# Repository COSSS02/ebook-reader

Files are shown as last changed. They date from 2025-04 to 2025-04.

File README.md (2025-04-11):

# E-book Reader

This is my implementation of an E-book Reader, made entirely in Autodesk Fusion.

## Device
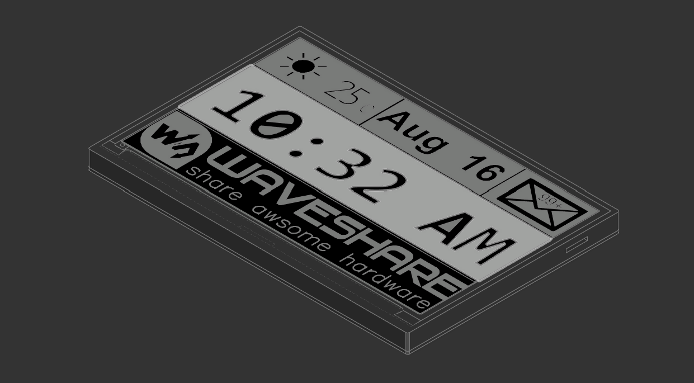
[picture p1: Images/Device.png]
Device


## Exploded View
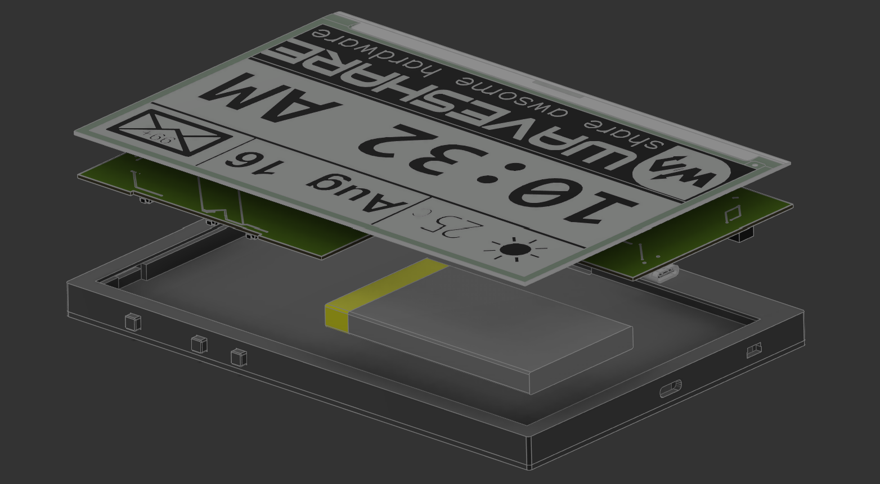
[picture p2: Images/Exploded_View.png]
Exploded


## PCB
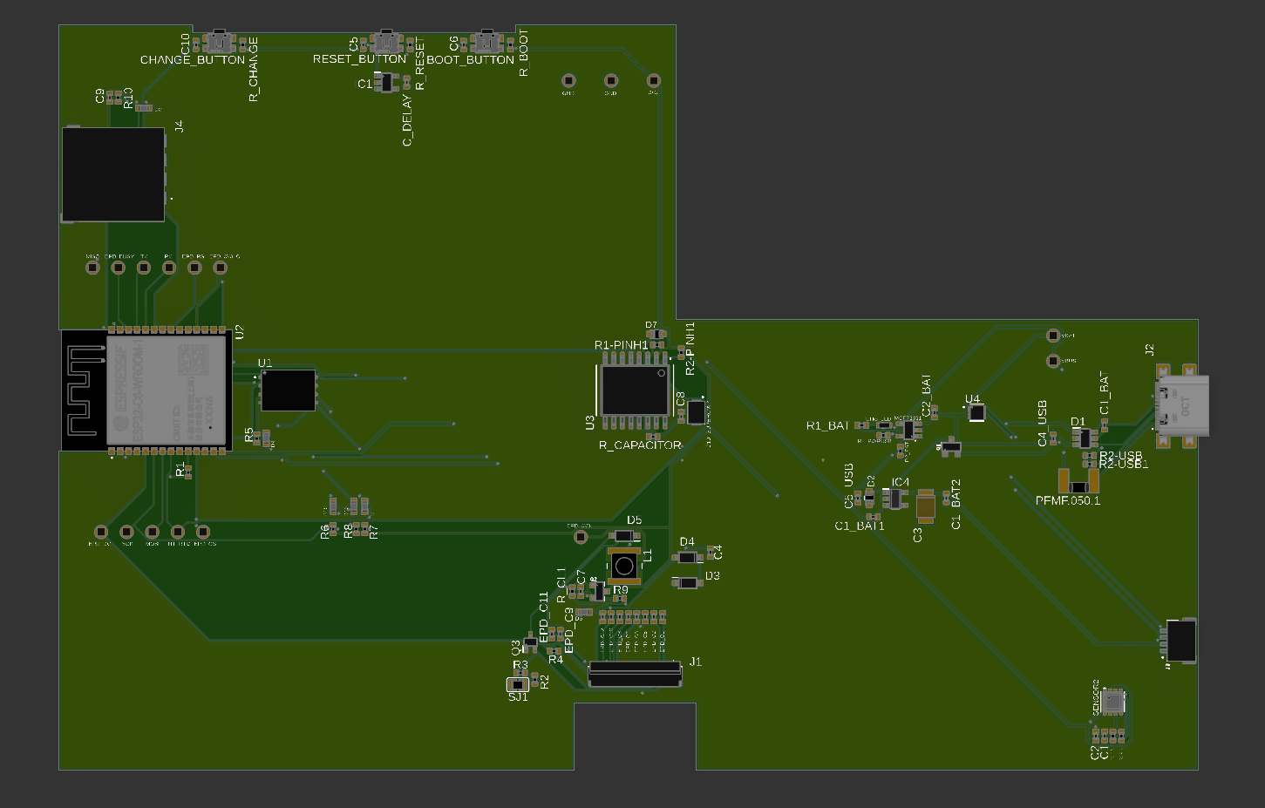
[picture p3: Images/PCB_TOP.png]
PCB


## Block Diagram
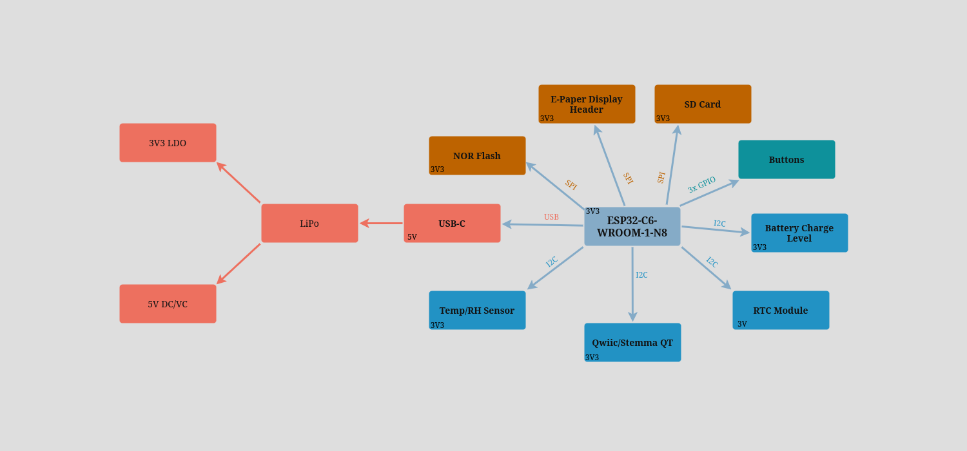
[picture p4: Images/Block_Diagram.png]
Diagram


## ESP32-C6 Pin Connections

### E-Paper Display
- MOSI --> GPIO4
- SCK --> GPIO5
- RESET --> GPIO15
- BUSY --> GPIO16
- CS --> GPIO17
- DC --> GPIO18

### SD Card
- CLK --> GPIO6
- CMD --> GPIO7
- DATA0 --> GPIO8
- DATA1 --> GPIO9
- DATA2 --> GPIO10
- DATA3 --> GPIO11

### NOR Flash Memory
- MOSI --> GPIO4
- MISO --> GPIO3
- CLK --> GPIO5
- CS --> GPIO2

### Temp/RH Sensor
- SDA --> GPIO19
- SCL --> GPIO20

### RTC Module
- SDA --> GPIO19
- SCL --> GPIO20

### Qwiic / Stemma QT
- SDA --> GPIO19
- SCL --> GPIO20

### Battery Charge Level
- SDA --> GPIO19
- SCL --> GPIO20

### Buttons
- Reset --> GPIO0
- Boot --> GPIO1

## Bill of Materials

| Component | Datasheet |
|---|---|
| ESP32-C6-WROOM-1-N8 | [Mouser](https://mou.sr/42swLfH) |
| FH34SRJ-24S-0.5SH | [Mouser](https://mou.sr/43Cr53R) |
| XC6220A331MR-G | [Mouser](https://mou.sr/4ieKgVa) |
| MAX17048G+T10 | [Mouser](https://mou.sr/3FWR5wY) |
| W25Q512JVEIQ | [Mouser](https://mou.sr/42vsB6J) |
| USB4110-GF-A | [Mouser](https://mou.sr/4iUMo5l) |
| USBLC6-2SC6Y | [Mouser](https://mou.sr/42lyiTK) |
| DS3231SN# | [Mouser](https://mou.sr/42jhNr4) |
| BME680 | [Mouser](https://mou.sr/42kgEzJ) |
| PFMF.050.2 | [Mouser](https://mou.sr/4cjORnD) |
| BD5229G-TR | [Mouser](https://mou.sr/3EckiDF) |
| MBR0530-TP | [Mouser](https://mou.sr/4i9Ddgn) |
| DMG2305UX-7 | [Mouser](https://mou.sr/4ci24gy) |
| PGB1010603MR | [Mouser](https://mou.sr/3Yg9sDe) |
| Adafruit 4208 | [Mouser](https://mou.sr/4lcY19f) |
| SD0805S020S1R0 | [Mouser](https://mou.sr/4cljSYj) |
| SI1308EDL-T1-GE3 | [Mouser](https://mou.sr/4lj7JXH) |
| MCP73831-2ACI/MC | [Mouser](https://mou.sr/3XJhnsM) |

## Hardware Description

### Main Controller

    ESP32-C6-WROOM-1-N8: RISC-V based microcontroller with WiFi 6 and Bluetooth 5.0 LE

    Operating Voltage: 3.3V

    Clock Speed: 160MHz

### Memory Configuration

    External NOR Flash: W25Q512JVEIQ (64MB capacity)

    Interface: SPI (Serial Peripheral Interface)

### Power Management System

    Primary Regulator: XC6220A331MR-G (3.3V LDO)

    Battery Charger: MCP73831 (Li-Po charging controller)

    Fuel Gauge: MAX17048G+T10 (Battery monitoring IC)

    Power Path Protection:

        MBR0530 Schottky diodes (x3)

        SI1308EDL-T1-GE3 MOSFET

### Display System

    E-Paper Display Interface: Dedicated header with ESD protection

    Display Driver Circuit: Custom EPD power management

    Control Signals:

        EPD_RST (Reset)

        EPD_BUSY (Status)

        EPD_DC (Data/Command)

        EPD_CS (Chip Select)

### Environmental Sensing

    BME688: Integrated environmental sensor with:

        Temperature

        Humidity

        Barometric pressure

        Air quality (VOC detection)

    Interface: I2C (Qwiic/Stemma QT compatible)

### Real-Time Clock

    DS3231SN: High-precision RTC with:

        ±2ppm accuracy

        Integrated temperature compensation

        Battery backup support

        Square wave/interrupt output

### Connectivity Interfaces USB

    Type-C Connector: USB 2.0 compliant

    ESD Protection: USBLC6-2SC6Y

    Data Lines:

        USB_D+

        USB_D-

### Expansion Ports

    Qwiic/Stemma QT: 4-pin I2C connector

    SD Card Slot: Supports standard SD cards

        Interface: SPI mode

        Detection switch included

### Debugging Interfaces

    Test Points: 17 accessible test points

### Power Specifications

    Input Voltage: 5V via USB-C

    Battery Voltage: 3.7V Li-Po

    Power Tree:

        Primary 3.3V rail for digital components

        Dedicated 3.3V rail for display

        RTC backup power circuit

### Mechanical Interfaces

    24-pin FH34SRJ Connector: Display interface

    Tactile Buttons:

        Reset button

        Boot/IO button

        Custom function buttons

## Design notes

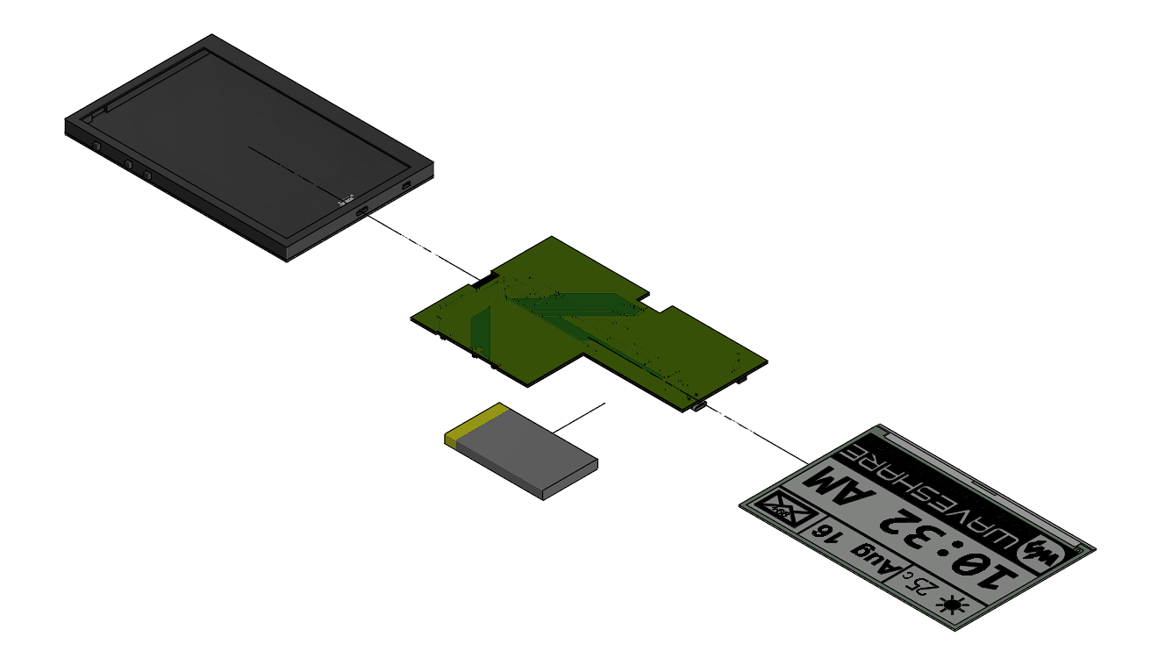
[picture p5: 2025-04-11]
Images/Exploded_View_Drawing.png

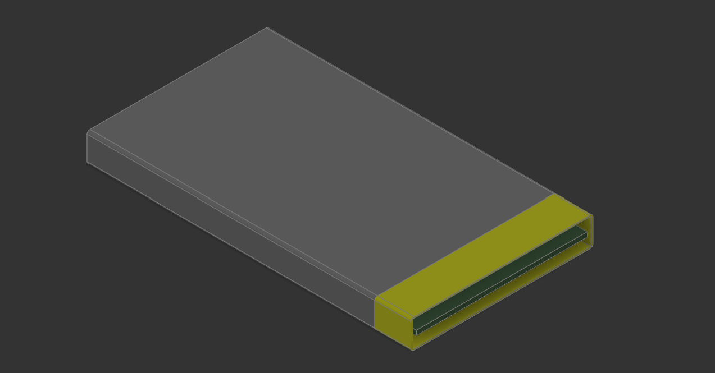
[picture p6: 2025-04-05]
Images/Battery.png

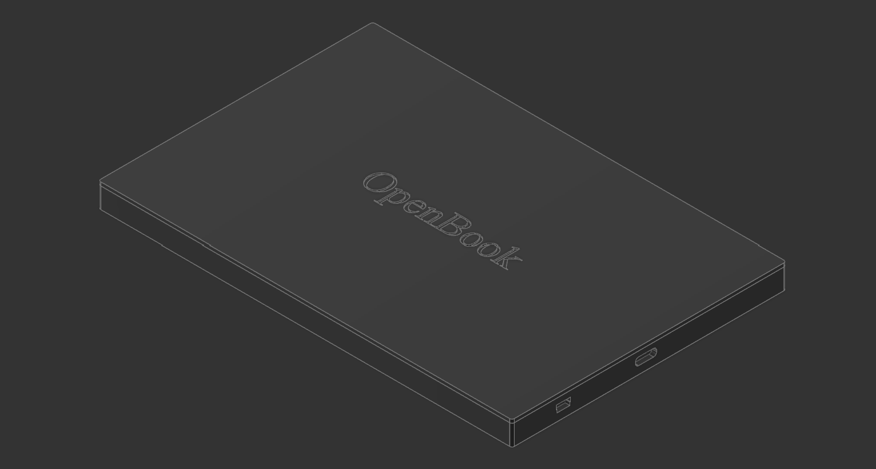
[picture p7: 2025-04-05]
Images/Enclosure.png

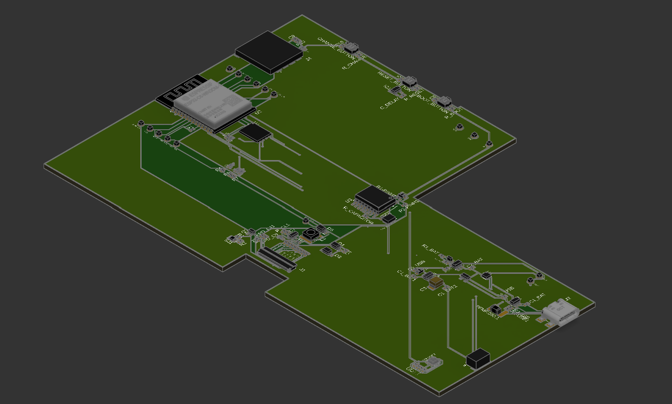
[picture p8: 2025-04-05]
Images/PCB.png

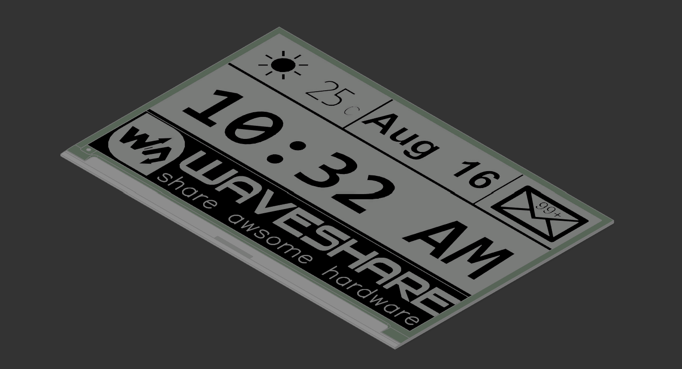
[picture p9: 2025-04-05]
Images/Display.png

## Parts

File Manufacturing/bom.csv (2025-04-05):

Qty | Value | Device | Package | Parts | Description | ARROW_PART_NUMBER | ARROW_PRICE-STOCK | AVAILABILITY | CHECK_PRICES | COPYRIGHT | DESCRIPTION | FOOPRINT | FOOTPRINT | HEIGHT | MANUFACTURER_NAME | MANUFACTURER_PART_NUMBER | MF | MFR_NAME | MOUSER_PART_NUMBER | MOUSER_PRICE-STOCK | MOUSER_TESTING_PART_NUMBER | MOUSER_TESTING_PRICE-STOCK | MP | PACKAGE | POPULARITY | PRICE | PROD_ID | PURCHASE-URL | SNAPEDA_LINK | SPICEPREFIX | VAL | VALUE
1 |  | ADAFRUIT_LEDCHIP-LED0603 | ADAFRUIT_CHIP-LED0603 | CHG_LED | LED
1 |  | SJ | SJ | SJ1 | SMD solder JUMPER |  |  |  |  |  |  |  |  |  |  |  |  |  |  |  |  |  |  |  | 3
1 | 0.1uF/50V | ESP32_WROVER_EAGLE-LTSPICE_C | EAGLE-LTSPICE_C0402 | EPD_C5 | CAPACITOR, European symbol
1 | 0.47 | ESP32_WROVER_EAGLE-LTSPICE_R | ESP32_WROVER_EAGLE-LTSPICE_R0402 | R3 | RESISTOR, European symbol
1 | 100K | ESP32_WROVER_EAGLE-LTSPICE_R | ESP32_WROVER_EAGLE-LTSPICE_R0402 | R1_PWRUSB | RESISTOR, European symbol
8 | 100nF | ESP32_WROVER_EAGLE-LTSPICE_C | EAGLE-LTSPICE_C0402 | C1, C2, C4_USB, C6, C8, C9, C10, C_DELAY | CAPACITOR, European symbol
1 | 100uF TANT | RCL_CPOL-EUCT3528 | RCL_CT3528 | C3 | POLARIZED CAPACITOR, European symbol |  |  |  |  |  |  |  |  |  |  |  |  |  |  |  |  |  |  |  | 0 |  |  |  |  | C
2 | 10K | ESP32_WROVER_EAGLE-LTSPICE_R | ESP32_WROVER_EAGLE-LTSPICE_R0402 | R1, R4 | RESISTOR, European symbol
14 | 10k | ESP32_WROVER_EAGLE-LTSPICE_R | ESP32_WROVER_EAGLE-LTSPICE_R0402 | R1-PINH, R1-PINH1, R2-PINH, R2-PINH1, R5, R6, R7, R8, R9, R10, R_BOOT, R_CHANGE, R_CL1, R_RESET | RESISTOR, European symbol
1 | 10uF | ESP32_WROVER_EAGLE-LTSPICE_C | EAGLE-LTSPICE_C0402 | C7 | CAPACITOR, European symbol
1 | 112A-TAAR-R03_ATTEND | 112A-TAAR-R03_ATTEND | 112ATAARR03ATTEND | J4 | Micro SD Card Socket, Push-Push Type, Top Mount, SMT, H=1.83mm, 10u |  |  |  |  |  | Micro SD Card Socket | Push-Push Type | Top Mount | SMT | H=1.83mm | 10u |  |  | 1.9mm | ATTEND | 112A-TAAR-R03 ATTEND
1 | 15 | ESP32_WROVER_EAGLE-LTSPICE_R | ESP32_WROVER_EAGLE-LTSPICE_R0402 | R_CAPACITOR | RESISTOR, European symbol
1 | 1uF | ESP32_WROVER_EAGLE-LTSPICE_C | EAGLE-LTSPICE_C0402 | C5 | CAPACITOR, European symbol
9 | 1uF/50V | ESP32_WROVER_EAGLE-LTSPICE_C | EAGLE-LTSPICE_C0402 | EPD_C1, EPD_C2, EPD_C6, EPD_C7, EPD_C8, EPD_C9, EPD_C10, EPD_C11, EPD_C12 | CAPACITOR, European symbol
1 | 2.2 | ESP32_WROVER_EAGLE-LTSPICE_R | ESP32_WROVER_EAGLE-LTSPICE_R0402 | R2 | RESISTOR, European symbol
1 | 200 | ESP32_WROVER_EAGLE-LTSPICE_R | ESP32_WROVER_EAGLE-LTSPICE_R0402 | R1_BAT | RESISTOR, European symbol
2 | 20V/4.2A/52mO/1.4W | ESP32_WROVER_SPARKFUN-DISCRETESEMI_MOSFET_PCH | ESP32_WROVER_SPARKFUN-DISCRETESEMI_SOT23-3 | Q1, Q2 | P-channel MOSFETs |  |  |  |  |  |  |  | DMG2305UX-7
1 | 2K | ESP32_WROVER_EAGLE-LTSPICE_R | ESP32_WROVER_EAGLE-LTSPICE_R0402 | R2_BAT | RESISTOR, European symbol
5 | 4.7uF | ESP32_WROVER_EAGLE-LTSPICE_C | EAGLE-LTSPICE_C0402 | C1_BAT, C1_BAT1, C1_BAT2, C2_BAT, C5_USB | CAPACITOR, European symbol
1 | 4.7uF/25V | ESP32_WROVER_EAGLE-LTSPICE_C | EAGLE-LTSPICE_C0402 | C4 | CAPACITOR, European symbol
2 | 5k1 | ESP32_WROVER_EAGLE-LTSPICE_R | ESP32_WROVER_EAGLE-LTSPICE_R0402 | R2-USB, R2-USB1 | RESISTOR, European symbol
1 | 744043680IND_4828-WE-TPC_WRE | 744043680IND_4828-WE-TPC_WRE | IND_4828-WE-TPC_WRE | L1 |  |  |  |  |  | Copyright (C) 2024 Ultra Librarian. All rights reserved. |  |  |  |  |  | 744043680 |  | Wurth Electronics |  |  |  |  |  |  |  |  |  |  |  |  | 68uH
1 | BD5229G-TR | BD5229G-TR | SOT95P280X125-5N | IC1 | Voltage Detector with Adjustable Delay Time: CMOS processes are utilized to develop high precision, low current consumption CMOS reset ICs that allow arbitrary setting of the delay time. The extensive lineup includes both Nch Open Drain and CMOS output types in a wide range of detection voltages (from 2.3V to 6.0V, in 0.1V steps), enabling selection of the ideal solution based on customer requirements. In addition, the entire series is of course both lead-free and RoHS-compliant. |  |  |  |  |  | Voltage Detector with Adjustable Delay Time: CMOS processes are utilized to develop high precision | low current consumption CMOS reset ICs that allow arbitrary setting of the delay time. The extensive lineup includes both Nch Open Drain and CMOS output types in a wide range of detection voltages (from 2.3V to 6.0V | in 0.1V steps) | enabling selection of the ideal solution based on customer requirements. In addition | the entire series is of course both lead-free and RoHS-compliant. |  |  | 1.25mm | ROHM Semiconductor | BD5229G-TR |  |  | 755-BD5229G-TR | https://www.mouser.co.uk/ProductDetail/ROHM-Semiconductor/BD5229G-TR?qs=4kLU8WoGk0vvnhrrYwdszw%3D%3D
3 | BUTTON_CUSYOMV1FINAL_BUTT | BUTTON_CUSYOMV1FINAL_BUTT | MYBUTTON | BOOT_BUTTON, CHANGE_BUTTON, RESET_BUTTON
1 | CPH3225A | CPH3225A | CAPCP3225X100N | C10_SUPERCAP | Cap 0.011F 3.3V 1210 Flat Check availability |  |  | Not in stock | https://www.snapeda.com/parts/CPH3225A/Seiko+Instruments/view-part/?ref=eda |  | 11 mF (EDLC) Supercapacitor 3.3 V 1210 (3225 Metric) - - |  |  |  |  |  | Seiko Instruments |  |  |  |  |  | CPH3225A | 1210 Seiko |  | None |  | https://www.snapeda.com/api/url_track_click_mouser/?unipart_id=562593&manufacturer=Seiko Instruments&part_name=CPH3225A&search_term=None | https://www.snapeda.com/parts/CPH3225A/Seiko+Instruments/view-part/?ref=snap
1 | DS3231SN# | DS3231SN# | SOIC127P1032X265-16N | U3 | Real Time Clock Serial 16-Pin SOIC W T/R Check availability |  |  | In Stock | https://www.snapeda.com/parts/DS3231SN%23/Analog+Devices/view-part/?ref=eda |  | Extremely Accurate I²C-Integrated RTC/TCXO/Crystal |  |  |  |  |  | Analog Devices |  |  |  |  |  | DS3231SN# | SOIC-16 Maxim |  | None |  | https://www.snapeda.com/api/url_track_click_mouser/?unipart_id=99048&manufacturer=Analog Devices&part_name=DS3231SN#&search_term=None | https://www.snapeda.com/parts/DS3231SN%23/Analog+Devices/view-part/?ref=snap
1 | ESP32-C6-WROOM-1-N8 | ESP32-C6-WROOM-1-N8 | XCVR_ESP32-C6-WROOM-1-N8 | U2 | Check availability |  |  | In Stock | https://www.snapeda.com/parts/ESP32-C6-WROOM-1-N8/Espressif+Systems/view-part/?ref=eda |  | Multiprotocol Modules ESP32-C6 module | Wi-Fi 6 in 2.4 GHz band | Bluetooth 5 | Zigbee 3.0 and Thread. ESP34-WROOM Compatible - ENGINEERING SAMPLE |  |  |  |  |  | Espressif Systems |  |  |  |  |  | ESP32-C6-WROOM-1-N8 | None |  | None |  |  | https://www.snapeda.com/parts/ESP32-C6-WROOM-1-N8/Espressif+Systems/view-part/?ref=snap
1 | ESP32C6_VARISTORCN1812 | ESP32C6_VARISTORCN1812 | ESP32C6_VARISTOR_CT/CN1812 | PFMF.050.1 | VARISTOR |  |  |  |  |  |  |  |  |  |  |  |  |  |  |  |  |  |  |  | 0
2 | ESP32_WROVER_AVX---SD0805S020S1R0_AVX_SD0805S020S1R0_0_0 | ESP32_WROVER_AVX---SD0805S020S1R0_AVX_SD0805S020S1R0_0_0 | ESP32_WROVER_AVX---SD0805S020S1R0_AVX_SD0805S020S1R0_0 | D2, D7 | Schottky Barrier Rectifier Diode |  |  |  |  |  |  | SD0805S020S1R0
1 | ESP32_WROVER_BME680_BME680 | ESP32_WROVER_BME680_BME680 | ESP32_WROVER_BME680_PSON80P300X300X100-8N | SENSOR2 | Integrated Environmental Unit |  |  | Unavailable |  |  | Integrated Environmental Unit |  | BME688 |  |  |  | Bosch Sensortec |  |  |  |  |  | BME680 | LGA-8 Bosch Tools |  | None
1 | ESP32_WROVER_SPARKFUN-IC-POWER_MCP73831 | ESP32_WROVER_SPARKFUN-IC-POWER_MCP73831 | ESP32_WROVER_SPARKFUN-IC-POWER_SOT23-5 | MCP73831 | MCP73831T Li-Ion, Li-Pol Controller |  |  |  |  |  |  |  |  |  |  |  |  |  |  |  |  |  |  |  |  |  | IC-09995
1 | FH34SRJ-24S-0.5SH_99_ | FH34SRJ-24S-0.5SH_99_ | FH34SRJ24S05SH99 | J1 | (0.50mm) Surface Mount, Right Angle |  |  |  |  |  | 24 Position FFC | FPC Connector Contacts | (0.50mm) Surface Mount | Right Angle |  |  | 1.1mm | Hirose | FH34SRJ-24S-0.5SH(99) |  |  | 798-FH34SRJ24S05SH99 | https://www.mouser.co.uk/ProductDetail/Hirose-Connector/FH34SRJ-24S-0.5SH99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
1 | MAX17048G+T10 | MAX17048G+T10 | SON50P200X200X80-9N | U4 | Check availability |  |  | In Stock | https://www.snapeda.com/parts/MAX17048G+T10/Analog+Devices/view-part/?ref=eda |  | 3µA 1-Cell/2-Cell Fuel Gauge with ModelGauge |  |  |  |  |  | Analog Devices |  |  |  |  |  | MAX17048G+T10 | TDFN-8 Maxim |  | None |  | https://www.snapeda.com/api/url_track_click_mouser/?unipart_id=329239&manufacturer=Analog Devices&part_name=MAX17048G+T10&search_term=None | https://www.snapeda.com/parts/MAX17048G+T10/Analog+Devices/view-part/?ref=snap | X
3 | MBR0530MYSOD | MBR0530MYSOD | SOD3716X135N | D3, D4, D5 | ON SEMICONDUCTOR - MBR0530 - DIODE, SCHOTTKY, 0.5A, 30V, SOD-123
6 | PGB1010603MRMYDIOC | PGB1010603MRMYDIOC | DIOC1608X36N | D6, D8, D9, D10, D11, D12 | Check availability
1 | QWIIC_RIGHT_ANGLE | QWIIC_CONNECTORJS-1MM | JST04_1MM_RA | J3 | SparkFun I2C Standard Qwiic Connector |  |  |  |  |  |  |  |  |  |  |  |  |  |  |  |  |  |  |  |  |  | CONN-13694 |  |  |  |  | QWIIC_RIGHT_ANGLE
1 | SAMACSYS_PARTS_USB4110-GF-A | SAMACSYS_PARTS_USB4110-GF-A | SAMACSYS_PARTS_USB4110GFA | J2 | CONN USB 2.0 TYPE-C R/A SMT |  |  |  |  |  | CONN USB 2.0 TYPE-C R/A SMT |  |  | 3.26mm | GCT (GLOBAL CONNECTOR TECHNOLOGY) | USB4110-GF-A |  |  | 640-USB4110-GF-A | https://www.mouser.co.uk/ProductDetail/GCT/USB4110-GF-A?qs=KUoIvG%2F9IlYiZvIXQjyJeA%3D%3D
1 | SI1308EDL-T1-GE3 | SI1308EDL-T1-GE3 | SOT65P210X110-3N | Q3 | MOSFET N-Ch 30V 1.5A TrenchFET SC70 Vishay Si1308EDL-T1-GE3 N-channel MOSFET Transistor, 1.5 A, 30 V, 3-Pin SC-70 |  |  | In Stock | https://www.snapeda.com/parts/SI1308EDL-T1-GE3/Vishay+Siliconix/view-part/?ref=eda |  | Si1308EDL-T1-GE3 N-channel MOSFET Transistor | 1.5 A | 30 V | 3-Pin SC-70 | Siliconix / Vishay SI1308EDL-T1-GE3 |  |  |  |  |  | Vishay Siliconix |  |  |  |  |  | SI1308EDL-T1-GE3 | SOT-323 Vishay Semiconductor |  | None |  | https://www.snapeda.com/api/url_track_click_mouser/?unipart_id=274603&manufacturer=Vishay Siliconix&part_name=SI1308EDL-T1-GE3&search_term=None | https://www.snapeda.com/parts/SI1308EDL-T1-GE3/Vishay+Siliconix/view-part/?ref=snap
17 | TP | TP | TP20R | TP1, TP2, TP3, TP4, TP5, TP6, TP7, TP8, TP9, TP10, TP11, TP12, TP13, TP14, TP15, TP16, TP17 | Test pad
1 | USBLC6-2SC6Y | USBLC6-2SC6Y | SOT95P280X145-6N | D1 | Low Cap. ESD Protection Auto SOT-23-6 STMicroelectronics USBLC6-2SC6Y, Dual Uni-Directional TVS Diode Array, 6-Pin SOT-23 |  |  | In Stock | https://www.snapeda.com/parts/USBLC6-2SC6Y/STMicroelectronics/view-part/?ref=eda |  | 17V Clamp 5A (8/20µs) Ipp Tvs Diode Surface Mount SOT-23-6 |  |  |  |  |  | STMicroelectronics |  |  |  |  |  | USBLC6-2SC6Y | SOT-23-6 STMicroelectronics |  | None |  |  | https://www.snapeda.com/parts/USBLC6-2SC6Y/STMicroelectronics/view-part/?ref=snap
1 | W25Q512JVEIQ | W25Q512JVEIQ | SON127P600X800X80-9N | U1 | Check availability |  |  | In Stock | https://www.snapeda.com/parts/W25Q512JVEIQ/Winbond+Electronics/view-part/?ref=eda |  | FLASH - NOR Memory IC 512Mb (64M x 8) SPI - Quad I/O 133 MHz 8-WSON (8x6) |  |  |  |  |  | Winbond Electronics |  |  |  |  |  | W25Q512JVEIQ | Package |  | None |  |  | https://www.snapeda.com/parts/W25Q512JVEIQ/Winbond+Electronics/view-part/?ref=snap
1 | XC6220A331MR-G | XC6220A331MR-G | SOT95P280X120-5N | IC4 | LDO Voltage Regulators |  |  |  |  |  | LDO Voltage Regulators |  |  | 1.2mm | Torex | XC6220A331MR-G |  |  | 865-XC6220A331MR-G | https://www.mouser.co.uk/ProductDetail/Torex-Semiconductor/XC6220A331MR-G?qs=AsjdqWjXhJ8ZSWznL1J0gg%3D%3D

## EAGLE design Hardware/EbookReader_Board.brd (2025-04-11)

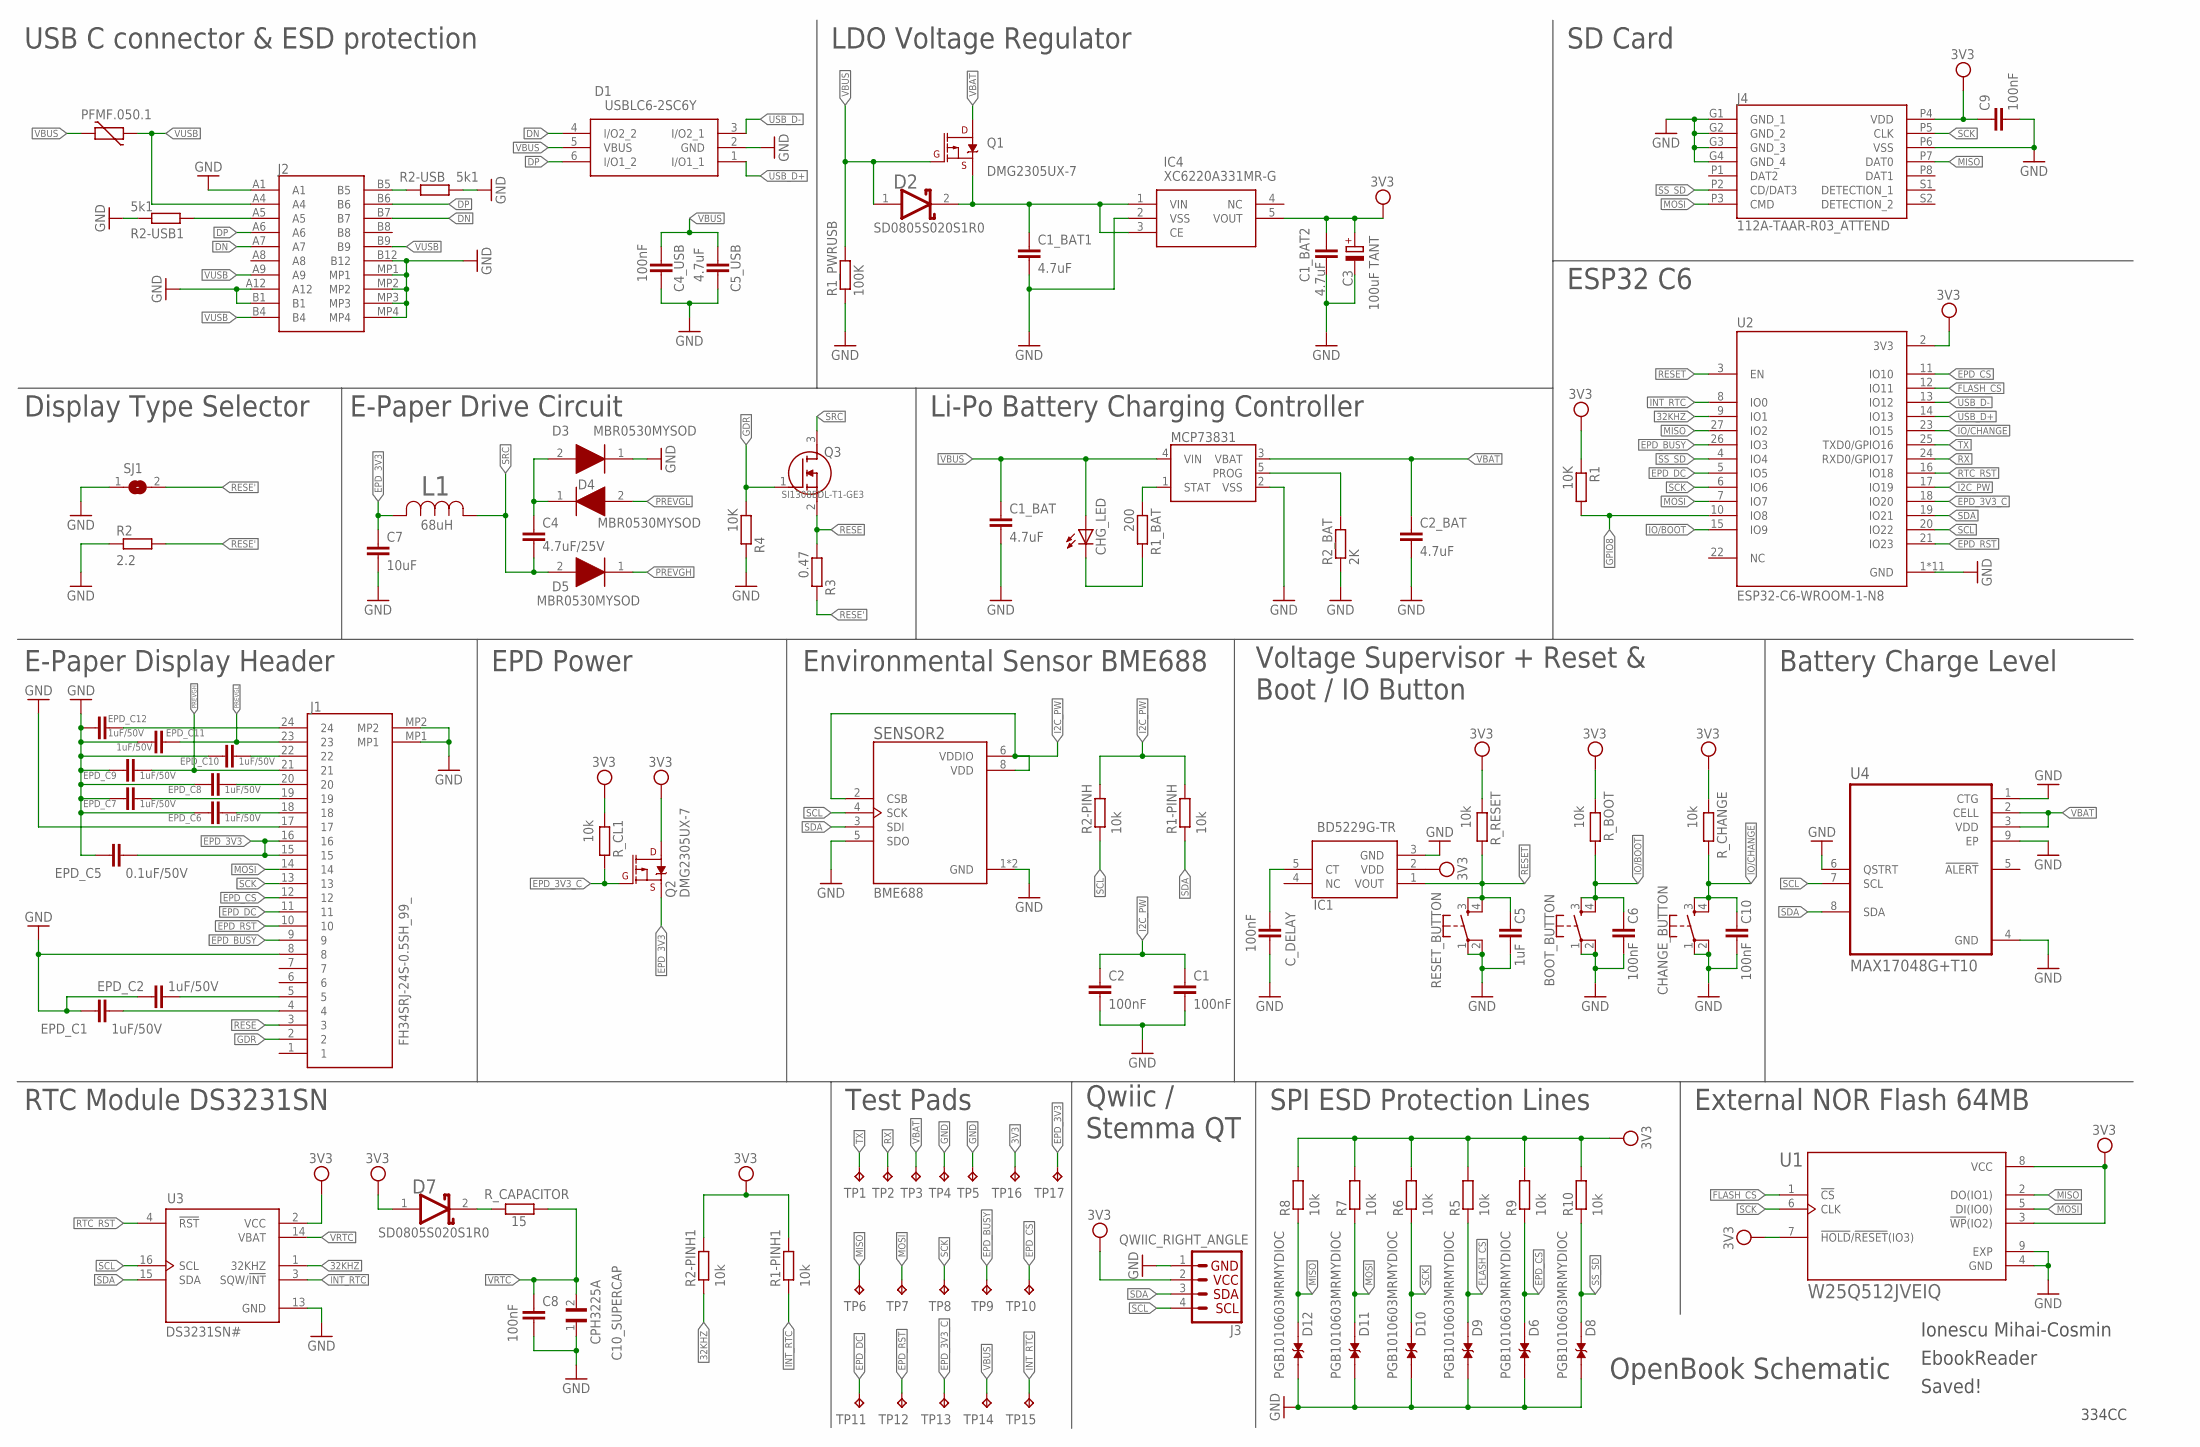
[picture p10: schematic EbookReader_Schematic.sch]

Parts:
BOOT_BUTTON: BUTTON_CUSYOMV1FINAL_BUTT; MYBUTTON
C1, C2, C4_USB, C6, C8, C9, C10: 100nF; EAGLE-LTSPICE_C0402
C1_BAT, C1_BAT1, C1_BAT2, C2_BAT, C5_USB: 4.7uF; EAGLE-LTSPICE_C0402
C3: 100uF TANT; RCL_CT3528
C4: 4.7uF/25V; EAGLE-LTSPICE_C0402
C5: 1uF; EAGLE-LTSPICE_C0402
C7: 10uF; EAGLE-LTSPICE_C0402
C10_SUPERCAP: CPH3225A; CAPCP3225X100N
CHANGE_BUTTON: BUTTON_CUSYOMV1FINAL_BUTT; MYBUTTON
CHG_LED: ADAFRUIT_LEDCHIP-LED0603; ADAFRUIT_CHIP-LED0603
C_DELAY: 100nF; EAGLE-LTSPICE_C0402
D1: USBLC6-2SC6Y; SOT95P280X145-6N
D2, D7: ESP32_WROVER_AVX---SD0805S020S1R0_AVX_SD0805S020S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; ESP32_WROVER_AVX---SD0805S020S1R0_AVX_SD0805S020S1R0_0
D3, D4, D5: MBR0530MYSOD; SOD3716X135N
D6, D8, D9, D10, D11, D12: PGB1010603MRMYDIOC; DIOC1608X36N
EPD_C1, EPD_C2, EPD_C6, EPD_C7, EPD_C8, EPD_C9, EPD_C10, EPD_C11, EPD_C12: 1uF/50V; EAGLE-LTSPICE_C0402
EPD_C5: 0.1uF/50V; EAGLE-LTSPICE_C0402
IC1: BD5229G-TR; SOT95P280X125-5N
IC4: XC6220A331MR-G; SOT95P280X120-5N
J1: FH34SRJ-24S-0.5SH_99_; FH34SRJ24S05SH99
J2: SAMACSYS_PARTS_USB4110-GF-A; SAMACSYS_PARTS_USB4110GFA
J3: QWIIC_RIGHT_ANGLE; JST04_1MM_RA
J4: 112A-TAAR-R03_ATTEND; 112ATAARR03ATTEND
L1: 744043680IND_4828-WE-TPC_WRE; IND_4828-WE-TPC_WRE
MCP73831: ESP32_WROVER_SPARKFUN-IC-POWER_MCP73831; ESP32_WROVER_SPARKFUN-IC-POWER_SOT23-5
PFMF.050.1: ESP32C6_VARISTORCN1812; ESP32C6_VARISTOR_CT/CN1812
Q1, Q2: 20V/4.2A/52mΩ/1.4W; ESP32_WROVER_SPARKFUN-DISCRETESEMI_SOT23-3
Q3: SI1308EDL-T1-GE3; SOT65P210X110-3N
R1, R4: 10K; ESP32_WROVER_EAGLE-LTSPICE_R0402
R1-PINH, R1-PINH1, R2-PINH, R2-PINH1, R5, R6, R7, R8, R9, R10: 10k; ESP32_WROVER_EAGLE-LTSPICE_R0402
R1_BAT: 200; ESP32_WROVER_EAGLE-LTSPICE_R0402
R1_PWRUSB: 100K; ESP32_WROVER_EAGLE-LTSPICE_R0402
R2: 2.2; ESP32_WROVER_EAGLE-LTSPICE_R0402
R2-USB, R2-USB1: 5k1; ESP32_WROVER_EAGLE-LTSPICE_R0402
R2_BAT: 2K; ESP32_WROVER_EAGLE-LTSPICE_R0402
R3: 0.47; ESP32_WROVER_EAGLE-LTSPICE_R0402
RESET_BUTTON: BUTTON_CUSYOMV1FINAL_BUTT; MYBUTTON
R_BOOT: 10k; ESP32_WROVER_EAGLE-LTSPICE_R0402
R_CAPACITOR: 15; ESP32_WROVER_EAGLE-LTSPICE_R0402
R_CHANGE: 10k; ESP32_WROVER_EAGLE-LTSPICE_R0402
R_CL1: 10k; ESP32_WROVER_EAGLE-LTSPICE_R0402
R_RESET: 10k; ESP32_WROVER_EAGLE-LTSPICE_R0402
SENSOR2: ESP32_WROVER_BME680_BME680; ESP32_WROVER_BME680_PSON80P300X300X100-8N
SJ1: SJ
TP1, TP2, TP3, TP4, TP5, TP6, TP7, TP8, TP9, TP10, TP11, TP12, TP13, TP14, TP15, TP16, TP17: TP; TP20R
U1: W25Q512JVEIQ; SON127P600X800X80-9N
U2: ESP32-C6-WROOM-1-N8; XCVR_ESP32-C6-WROOM-1-N8
U3: DS3231SN#; SOIC127P1032X265-16N
U4: MAX17048G+T10; SON50P200X200X80-9N

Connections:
3V3: C1_BAT2.1, C3.+, C9.1, D7.1 (ANODE), IC1.2 (VDD), IC4.5 (VOUT), J3.2, J4.P4 (VDD), Q2.1 (D), R1.1, R1-PINH1.2, R2-PINH1.2, R5.2, R6.2, R7.2, R8.2, R9.2, R10.2, R_BOOT.1, R_CHANGE.1, R_CL1.1, R_RESET.1, TP16.TP, U1.3 (!WP!(IO2)), U1.7 (!HOLD!/!RESET!(IO3)), U1.8 (VCC), U2.2 (3V3), U3.2 (VCC)
32KHZ: R2-PINH1.1, U2.9 (IO1), U3.1 (32KHZ)
DN: D1.4 (I/O2_2), J2.A7, J2.B7
DP: D1.6 (I/O1_2), J2.A6, J2.B6
EPD_3V3: C7.1, EPD_C5.1, J1.15, J1.16, L1.2, Q2.3 (S), TP17.TP
EPD_3V3_C: Q2.2 (G), R_CL1.2, TP13.TP, U2.18 (IO20)
EPD_BUSY: J1.9, TP9.TP, U2.26 (IO3)
EPD_CS: D6.2, J1.12, R9.1, TP10.TP, U2.11 (IO10)
EPD_DC: J1.11, TP11.TP, U2.5 (IO5)
EPD_RST: J1.10, TP12.TP, U2.21 (IO23)
FLASH_CS: D9.2, R5.1, U1.1 (!CS), U2.12 (IO11)
GDR: J1.2, Q3.1 (G), R4.1
GND: BOOT_BUTTON.1, BOOT_BUTTON.2, C1.2, C1_BAT.2, C1_BAT1.2, C1_BAT2.2, C2.2, C2_BAT.2, C3.-, C4_USB.2, C5.2, C5_USB.2, C6.2, C7.2, C8.2, C9.2, C10.2, C10_SUPERCAP.1, CHANGE_BUTTON.1, CHANGE_BUTTON.2, C_DELAY.2, D1.2 (GND), D3.1 (K), D6.1, D8.1, D9.1, D10.1, D11.1, D12.1, EPD_C1.2, EPD_C2.2, EPD_C5.2, EPD_C6.2, EPD_C7.2, EPD_C8.2, EPD_C9.2, EPD_C10.2, EPD_C11.2, EPD_C12.2, IC1.3 (GND), IC4.2 (VSS), J1.8, J1.17, J1.MP1, J1.MP2, J2.A1, J2.A12, J2.B1, J2.B12, J2.MP1, J2.MP2, J2.MP3, J2.MP4, J3.1, J4.G1 (GND_1), J4.G2 (GND_2), J4.G3 (GND_3), J4.G4 (GND_4), J4.P6 (VSS), MCP73831.2 (VSS), R1_PWRUSB.1, R2.1, R2-USB.2, R2-USB1.1, R2_BAT.1, R4.2, RESET_BUTTON.1, RESET_BUTTON.2, SENSOR2.1 (GND), SENSOR2.5 (SDO), SENSOR2.7 (GND), SJ1.1, TP4.TP, TP5.TP, U1.4 (GND), U1.9 (EXP), U2.1 (GND), U2.28 (GND), U2.29_1 (GND), U2.29_2 (GND), U2.29_3 (GND), U2.29_4 (GND), U2.29_5 (GND), U2.29_6 (GND), U2.29_7 (GND), U2.29_8 (GND), U2.29_9 (GND), U3.13 (GND), U4.1 (CTG), U4.4 (GND), U4.6 (QSTRT), U4.9 (EP)
GPIO8: R1.2, U2.10 (IO8)
I2C_PW: C1.1, C2.1, R1-PINH.2, R2-PINH.2, SENSOR2.2 (CSB), SENSOR2.6 (VDDIO), SENSOR2.8 (VDD), U2.17 (IO19)
INT_RTC: R1-PINH1.1, TP15.TP, U2.8 (IO0), U3.3 (SQW/!INT)
IO/BOOT: BOOT_BUTTON.3, BOOT_BUTTON.4, C6.1, R_BOOT.2, U2.15 (IO9)
IO/CHANGE: C10.1, CHANGE_BUTTON.3, CHANGE_BUTTON.4, R_CHANGE.2, U2.23 (IO15)
MISO: D12.2, J4.P7 (DAT0), R8.1, TP6.TP, U1.2 (DO(IO1)), U2.27 (IO2)
MOSI: D11.2, J1.14, J4.P3 (CMD), R7.1, TP7.TP, U1.5 (DI(IO0)), U2.7 (IO7)
unnamed: MCP73831.1 (STAT), R1_BAT.1
unnamed: J2.A5, R2-USB1.2
unnamed: J2.B5, R2-USB.1
unnamed: C1_BAT1.1, D2.2 (CATHODE), IC4.1 (VIN), IC4.3 (CE), Q1.3 (S)
unnamed: EPD_C2.1, J1.5
unnamed: EPD_C1.1, J1.4
unnamed: EPD_C6.1, J1.18
unnamed: EPD_C7.1, J1.19
unnamed: EPD_C8.1, J1.20
unnamed: EPD_C10.1, J1.22
unnamed: EPD_C12.1, J1.24
unnamed: CHG_LED.C, R1_BAT.2
unnamed: D7.2 (CATHODE), R_CAPACITOR.2
unnamed: MCP73831.5 (PROG), R2_BAT.2
unnamed: C4.1, D3.2 (A), D4.1 (K)
unnamed: C_DELAY.1, IC1.5 (CT)
PREVGH: D5.1 (K), EPD_C9.1, J1.21
PREVGL: D4.2 (A), EPD_C11.1, J1.23
RESE: J1.3, Q3.2 (S), R3.1
RESE': R2.2, R3.2, SJ1.2
RESET: C5.1, IC1.1 (VOUT), RESET_BUTTON.3, RESET_BUTTON.4, R_RESET.2, U2.3 (EN)
RTC_RST: U2.16 (IO18), U3.4 (!RST)
RX: TP2.TP, U2.24 (RXD0/GPIO17)
SCK: D10.2, J1.13, J4.P5 (CLK), R6.1, TP8.TP, U1.6 (CLK), U2.6 (IO6)
SCL: J3.4, R2-PINH.1, SENSOR2.4 (SCK), U2.20 (IO22), U3.16 (SCL), U4.7 (SCL)
SDA: J3.3, R1-PINH.1, SENSOR2.3 (SDI), U2.19 (IO21), U3.15 (SDA), U4.8 (SDA)
SRC: C4.2, D5.2 (A), L1.1, Q3.3 (D)
SS_SD: D8.2, J4.P2 (CD/DAT3), R10.1, U2.4 (IO4)
TX: TP1.TP, U2.25 (TXD0/GPIO16)
USB_D+: D1.1 (I/O1_1), U2.14 (IO13)
USB_D-: D1.3 (I/O2_1), U2.13 (IO12)
VBAT: C2_BAT.1, MCP73831.3 (VBAT), Q1.1 (D), TP3.TP, U4.2 (CELL), U4.3 (VDD)
VBUS: C1_BAT.1, C4_USB.1, C5_USB.1, CHG_LED.A, D1.5 (VBUS), D2.1 (ANODE), MCP73831.4 (VIN), PFMF.050.1.2, Q1.2 (G), R1_PWRUSB.2, TP14.TP
VRTC: C8.1, C10_SUPERCAP.2, R_CAPACITOR.1, U3.14 (VBAT)
VUSB: J2.A4, J2.A9, J2.B4, J2.B9, PFMF.050.1.1

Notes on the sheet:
USB C connector & ESD protection
LDO Voltage Regulator
SD Card
Display Type Selector
E-Paper Drive Circuit
Li-Po Battery Charging Controller
ESP32 C6
E-Paper Display Header
EPD Power
Environmental Sensor BME688
Voltage Supervisor + Reset & Boot / IO Button
Battery Charge Level
RTC Module DS3231SN
Test Pads
Qwiic / Stemma QT
SPI ESD Protection Lines
External NOR Flash 64MB
OpenBook Schematic
Ionescu Mihai-Cosmin
EbookReader
Saved!
334CC

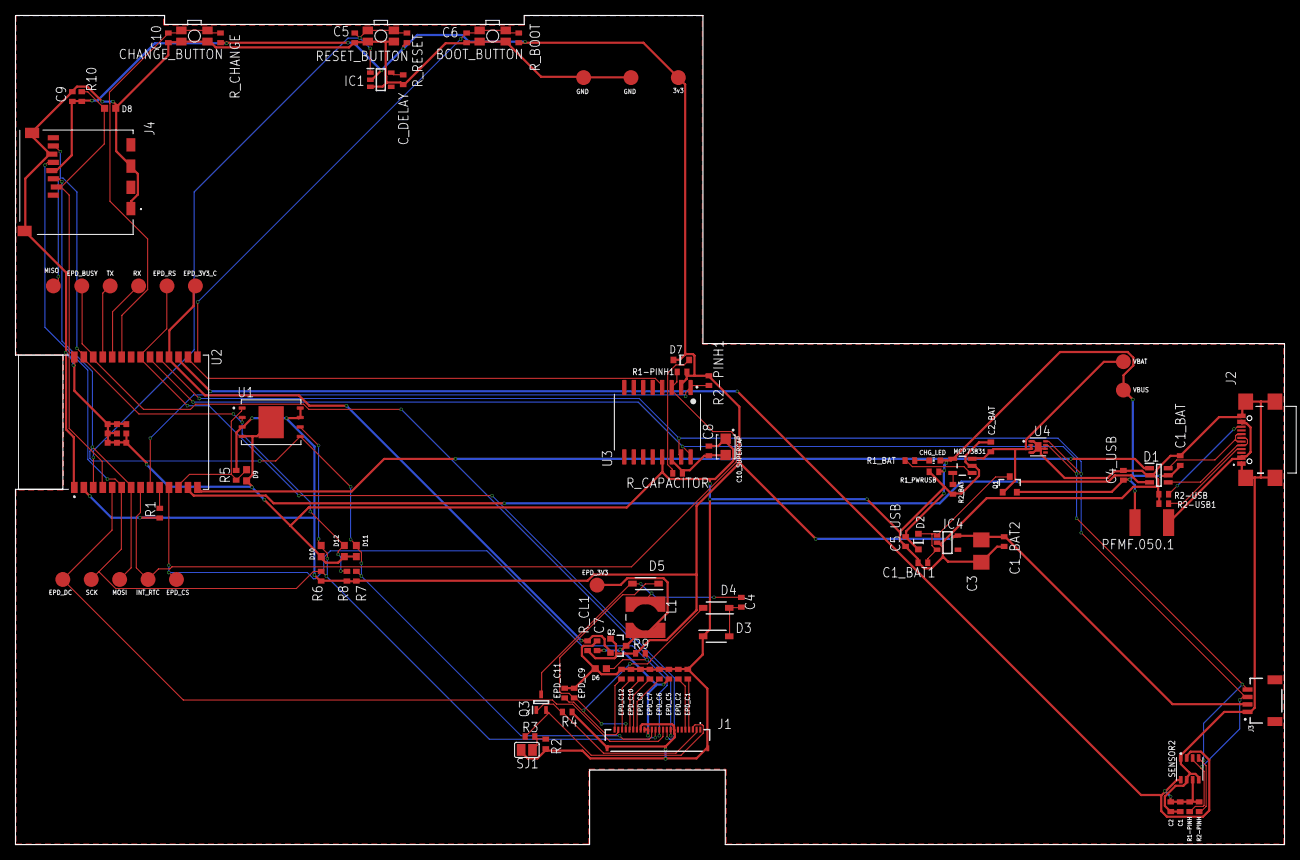
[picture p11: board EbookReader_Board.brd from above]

Board: 2 copper layers, 170.2 x 111.2 mm, 103 parts (0 on the bottom side), 55 nets.

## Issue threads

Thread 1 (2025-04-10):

Grosime PCB

Axagon6, 2025-04-10:
**PCB-ul trebuie să aibă grosimea de 1 mm.**
Cel din proiect are grosimea default de 1,6 mm. Este necesar să modifici grosimea stratului dielectric în DESIGN / Layer Stack

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

COSSS02, 2025-04-11:
Gata! Grosimea placii a fost modificata si modelul 3D a fost actualizat astfel incat toate porturile sa se alinieze cu sloturile carcasei.

Closed 2025-04-11.

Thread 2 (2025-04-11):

Plan de masă pe top si bottom

Axagon6, 2025-04-11:
Sunt câteva zone rămase neacoperite de planurile de masă. Dacă este posibil, creează noi planuri de masă.

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

COSSS02, 2025-04-11:
Acum planul de masa acopera intreaga placa, pe ambele layere TOP si BOTTOM.

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

Closed 2025-04-11.

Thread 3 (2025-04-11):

Text din silkscreen suprapus cu găuri sau paduri

Axagon6, 2025-04-11:
Modifică poziția textului pentru a evita suprapunerea cu găuri/paduri

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

COSSS02, 2025-04-11:
Textele problematice au fost mutate/redimensionate, acum nu mai exista suprapuneri.

Closed 2025-04-11.

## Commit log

2025-04-05 Added Hardware
    [EbookReader_Board.brd, EbookReader_Schematic.sch]
2025-04-05 Added Manufacturing
    [bom.csv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]
2025-04-11 Fixed Issues detected during the DVT phase
    [EbookReader_Board.brd]

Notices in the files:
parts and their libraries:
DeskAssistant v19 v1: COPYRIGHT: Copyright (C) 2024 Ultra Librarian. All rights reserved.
